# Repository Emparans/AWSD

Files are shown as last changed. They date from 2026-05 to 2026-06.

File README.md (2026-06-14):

# AWSD
### *Adventurer Who Solves Dungeons*

> Prototipo de robot autónomo para exploración de laberintos interactivos.

---

<div align="center">
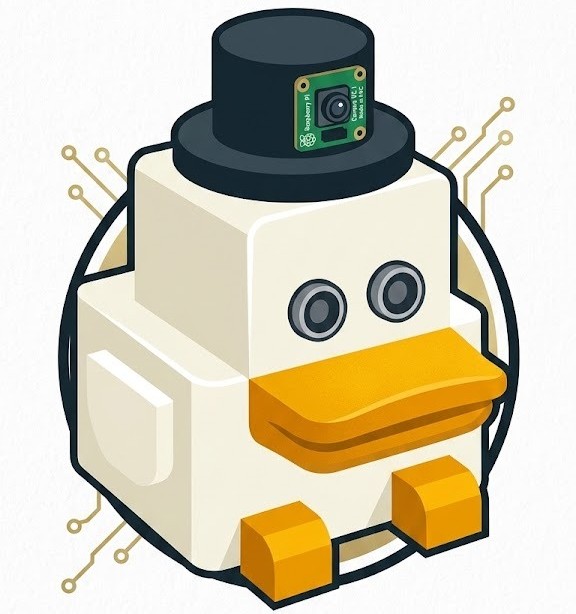
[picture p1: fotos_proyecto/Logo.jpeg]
LogoProyecto
  
</div>

# Descripción

AWSD (*Adventurer Who Solves Dungeons*) es un prototipo de robot autónomo diseñado para explorar laberintos de forma inteligente e interactiva. El proyecto combina robótica, visión artificial e interacción con el usuario para crear una experiencia inspirada en los videojuegos de aventuras.

Gracias a su cámara y a sus algoritmos de reconocimiento visual, el robot es capaz de analizar el entorno y localizar elementos importantes dentro del laberinto, como llaves necesarias para abrir puertas y avanzar en el recorrido.

Durante la exploración, AWSD encuentra distintos retos en forma de preguntas o pruebas que el usuario debe resolver para ayudar al robot a progresar. El objetivo del proyecto es integrar navegación autónoma, inteligencia artificial y gamificación en una experiencia educativa y entretenida.

---

# Foto Robot

<div align="center">
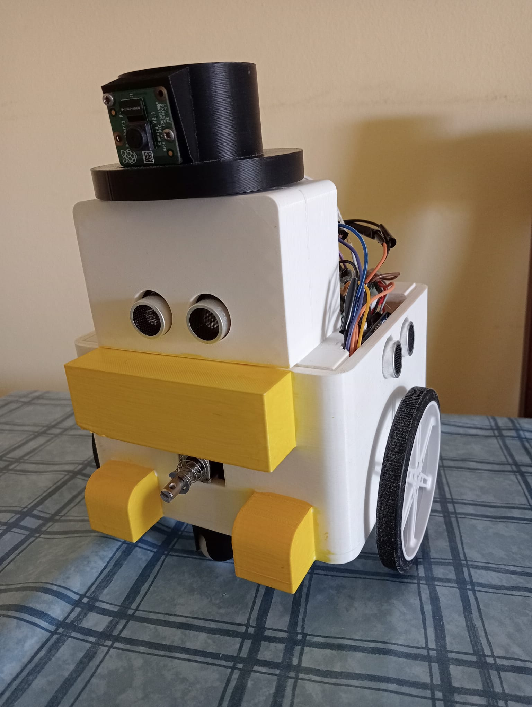
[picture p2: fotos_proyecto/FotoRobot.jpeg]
  
</div>

---

# Hardware

| Componente | Imagen | Descripción | Enlace |
|---|---|---|---|
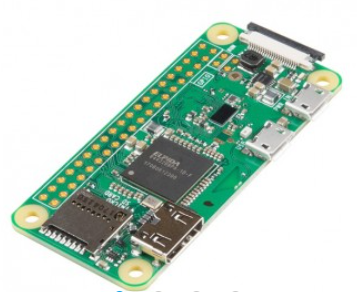
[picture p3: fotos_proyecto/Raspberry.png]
Raspberry
| **Raspberry Pi Zero W** |  | Cerebro del robot, gestiona la lógica y la conectividad Wifi. | [Ver Tienda](https://tienda.bricogeek.com/placas-raspberry-pi/1082-kit-basico-raspberry-pi-zero-wifi-microsd-32gb.html) |
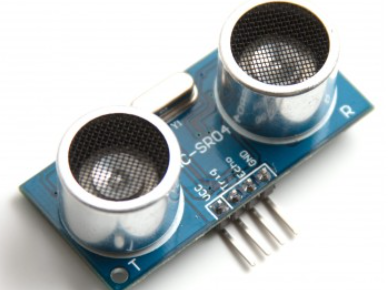
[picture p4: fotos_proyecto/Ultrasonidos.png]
Ultrasonidos
| **Sensor Ultrasonidos** |  | Mide las distancias para detectar las paredes del laberinto. | [Ver Tienda](https://tienda.bricogeek.com/sensores-distancia/741-sensor-de-distancia-por-ultrasonidos-hc-sr04.html) |
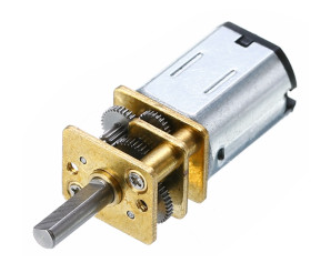
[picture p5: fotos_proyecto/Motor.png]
Motor
| **Motor N20 (6V 200 RPM)** |  | Motores con reductora metálica para el movimiento del chasis. | [Ver Tienda](https://tienda.bricogeek.com/motores-dc/1835-motor-n20-con-reductora-metalica-6v-200-rpm.html) |
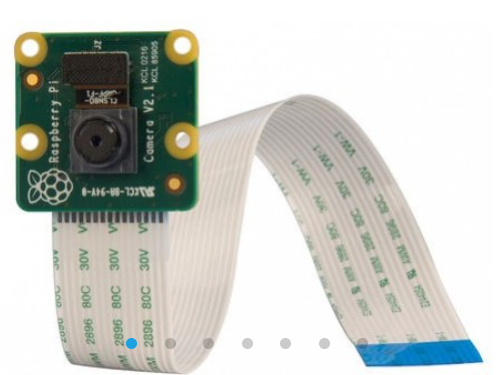
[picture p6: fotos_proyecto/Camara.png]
Camara
| **Cámara Raspberry Pi v2** |  | Captura imágenes en alta definición para la visión artificial. | [Ver Tienda](https://tienda.bricogeek.com/sensores-imagen/822-camara-raspberry-pi-v2-8-megapixels.html) |
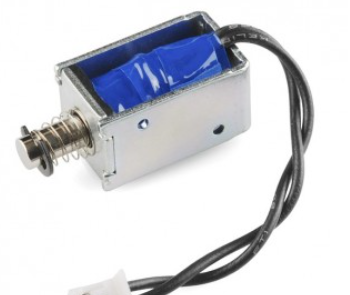
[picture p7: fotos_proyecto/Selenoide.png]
Selenoide
| **Solenoide 5V** |  | Actuador lineal para interactuar con los mecanismos del entorno. | [Ver Tienda](https://tienda.bricogeek.com/componentes/430-solenoide-5v.html) |
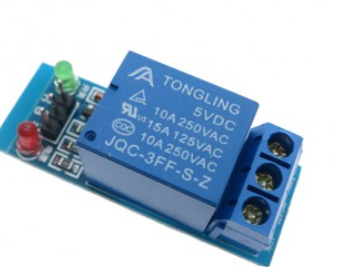
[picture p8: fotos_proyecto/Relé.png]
Relé
| **Módulo Relé** |  | Permite controlar el encendido del solenoide de forma segura. | [Ver Tienda](https://tienda.bricogeek.com/interruptores/1352-modulo-rele-5v.html) |
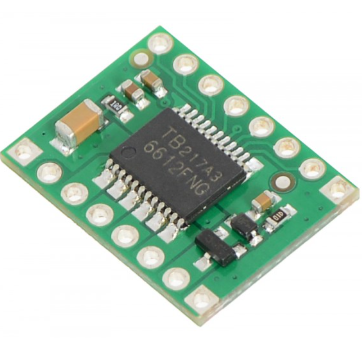
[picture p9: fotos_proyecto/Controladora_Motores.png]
ControladoraMotores
| **Controlador TB6612FNG** |  | Driver encargado de gestionar el sentido y velocidad de los motores. | [Ver Tienda](https://tienda.bricogeek.com/controladores-motores/999-controlador-de-motores-tb6612fng.html) |
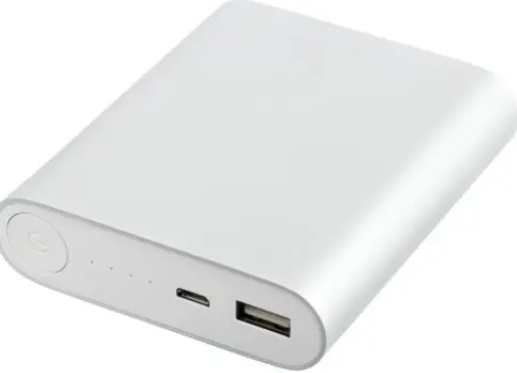
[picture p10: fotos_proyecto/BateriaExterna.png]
BateriaExterna
| **Batería Externa Anker** |  | Powerbank Slim encargada de alimentar la Raspberry Pi. | [Ver Tienda](https://www.amazon.es/Anker-PowerCore-Magnetic-Slim-B2C/dp/B099284SRR/) |
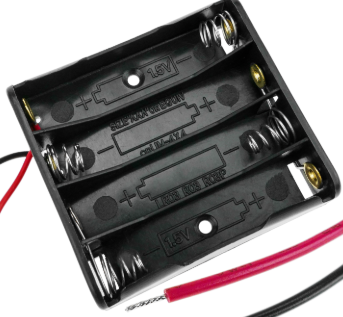
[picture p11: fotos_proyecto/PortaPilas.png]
PortaPilas
| **Porta Pilas 4xAA** |  | Soporte de baterías para la alimentación externa de los motores. | [Ver Tienda](https://tienda.bricogeek.com/componentes/160-base-para-baterias-4xaa.html) |
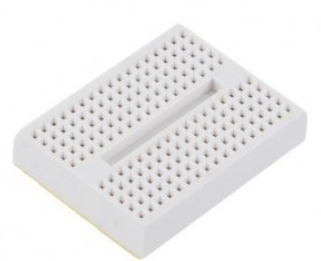
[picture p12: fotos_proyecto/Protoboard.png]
Protoboard
| **Mini Protoboard** |  | Placa de pruebas para realizar las conexiones eléctricas. | [Ver Tienda](https://tienda.bricogeek.com/herramientas-de-prototipado/211-mini-breadboard-adhesiva.html) |
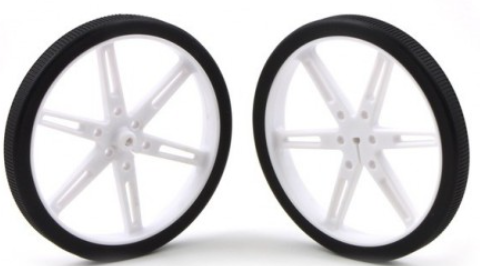
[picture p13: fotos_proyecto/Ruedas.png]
Ruedas
| **Ruedas (80x10mm)** |  | Pareja de ruedas principales acopladas a los motores N20. | [Ver Tienda](https://tienda.bricogeek.com/robotica/303-pareja-de-ruedas-80x10mm-blanco.html) |
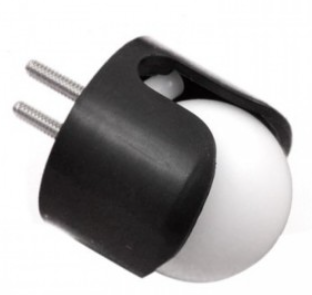
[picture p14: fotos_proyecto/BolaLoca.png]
RuedaLoca
| **Rueda Loca ABS** |  | Punto de apoyo pivotante trasero para dar estabilidad al robot. | [Ver Tienda](https://tienda.bricogeek.com/robotica/995-rueda-loca-plastico-abs-34.html) |

---

# Circuito Eléctrico

Diagrama de conexiones del sistema electrónico del robot.

<div align="center">
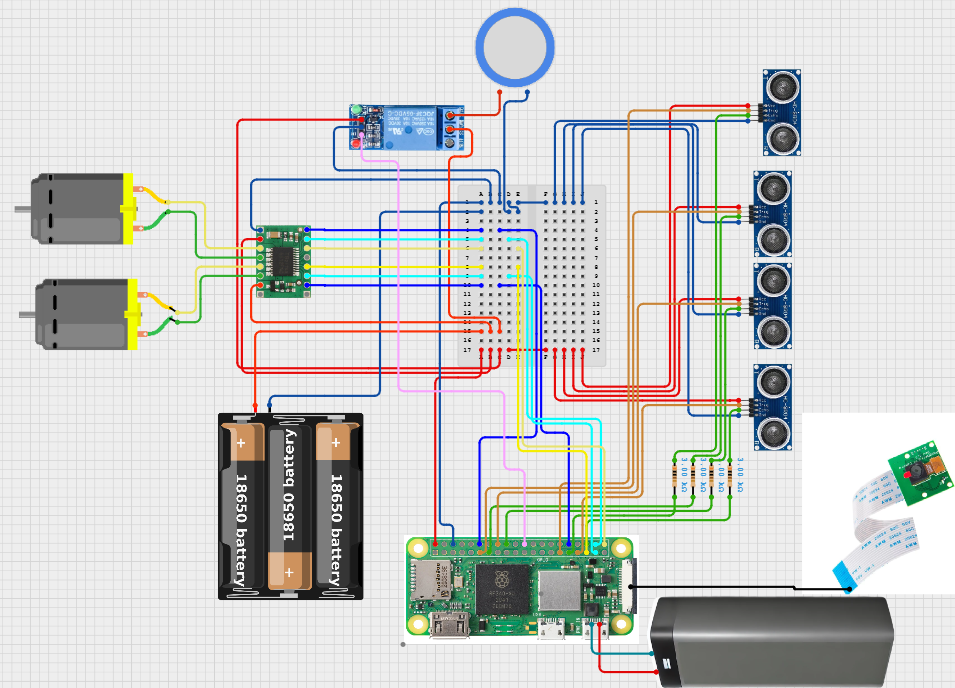
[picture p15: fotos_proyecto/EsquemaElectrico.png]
EsquemaElectrico
  
</div>

---

# Modelo 3D

Diseño 3D del chasis y componentes mecánicos del robot.

<div align="center">
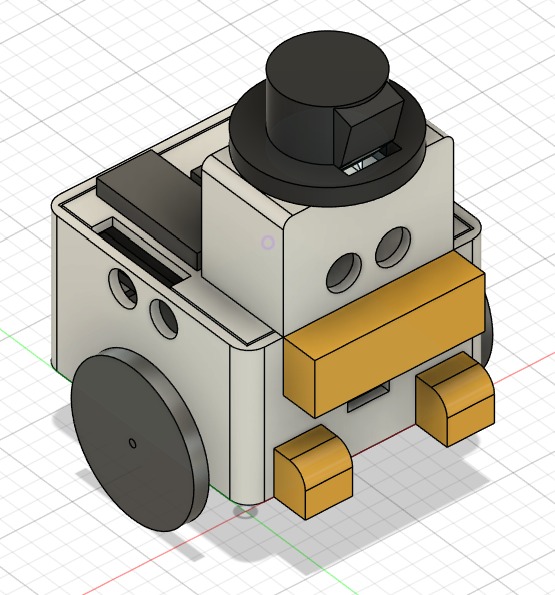
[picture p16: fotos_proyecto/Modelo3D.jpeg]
Modelo3D
  
</div>

---

# Arquitectura Software

Diagrama general de la arquitectura software del proyecto.

<div align="center">
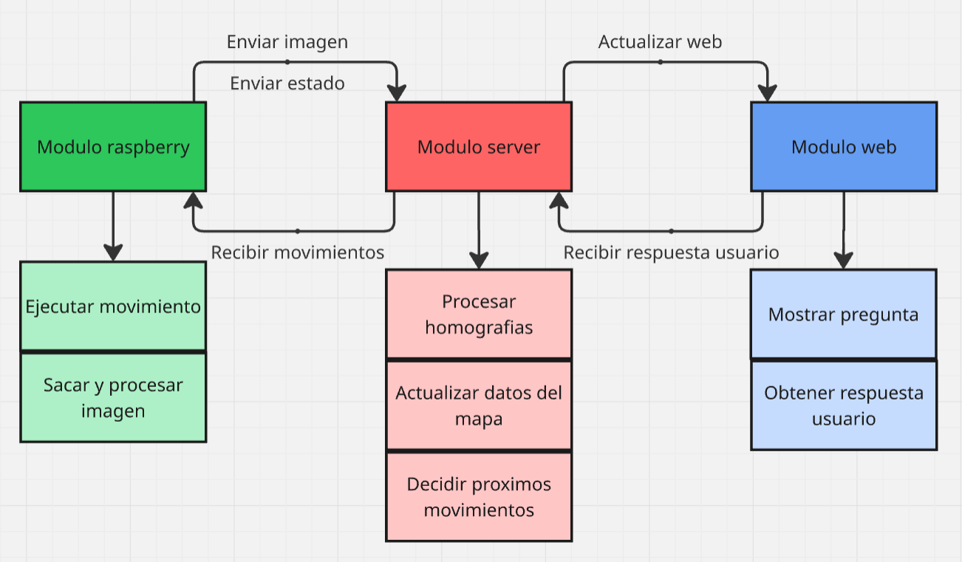
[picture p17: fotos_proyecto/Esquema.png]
Esquema
  
</div>

---

# Características

- Navegación autónoma en laberintos
- Reconocimiento visual mediante cámara
- Detección de llaves y puertas
- Interacción con el usuario mediante retos
- Arquitectura modular y escalable

---

# Referencias

- [@Rescue Maze Entry Presentation](https://www.youtube.com/watch?v=UpNFrBUcTxU&t=488s)
- [@The SECRET to Building a Maze Solving Robot](https://www.youtube.com/watch?v=Id-Xi8evfKU)
- [@Maze Navigating Robot Project With PicoBricks](https://picobricks.com/blogs/robotic-stem-projects/maze-solving-robot)
- [@Mec Robotics](https://www.micromice.org/)

---

# Autores

| Nombre | GitHub |
|---|---|
| Joan Aguilar Vilalta | [@JoanAV-H](https://github.com/JoanAV-H) |
| Gerard Benet Martinez | [@Gemarcx](https://github.com/Gemarcx) |
| Martí Barrio Galobardes | [@MBGit05](https://github.com/MBGit05) |
| Javier Emparan López | [@Emparans](https://github.com/Emparans) |

---

# Agradecimientos

Queremos agradecer a nuestros 3 profesores de la asignatura por ayudarnos en el proceso de creación de nuestro proyecto:

- Fernando Luis Vilariño Freire
- Carlos García Calvo
- Vernon Stanley Albayeros Duarte

# URL acceso a la web

¡Prueba la interfaz del proyecto en tiempo real! 

**[Acceder a la Web del Proyecto (Demo)](http://34.0.201.131:8080)**

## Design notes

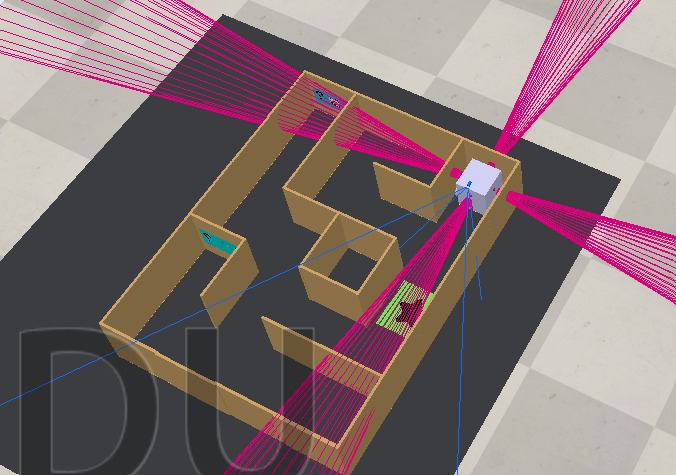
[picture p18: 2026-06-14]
Fotos_proyecto/FotoCoppelia.jpg

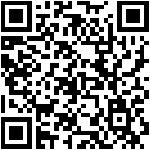
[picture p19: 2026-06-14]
Sim/texturas/preguntaEcuador.png

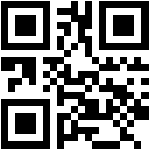
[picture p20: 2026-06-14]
Codigo/deteccion_de_objetos/Texturas/qr3.png

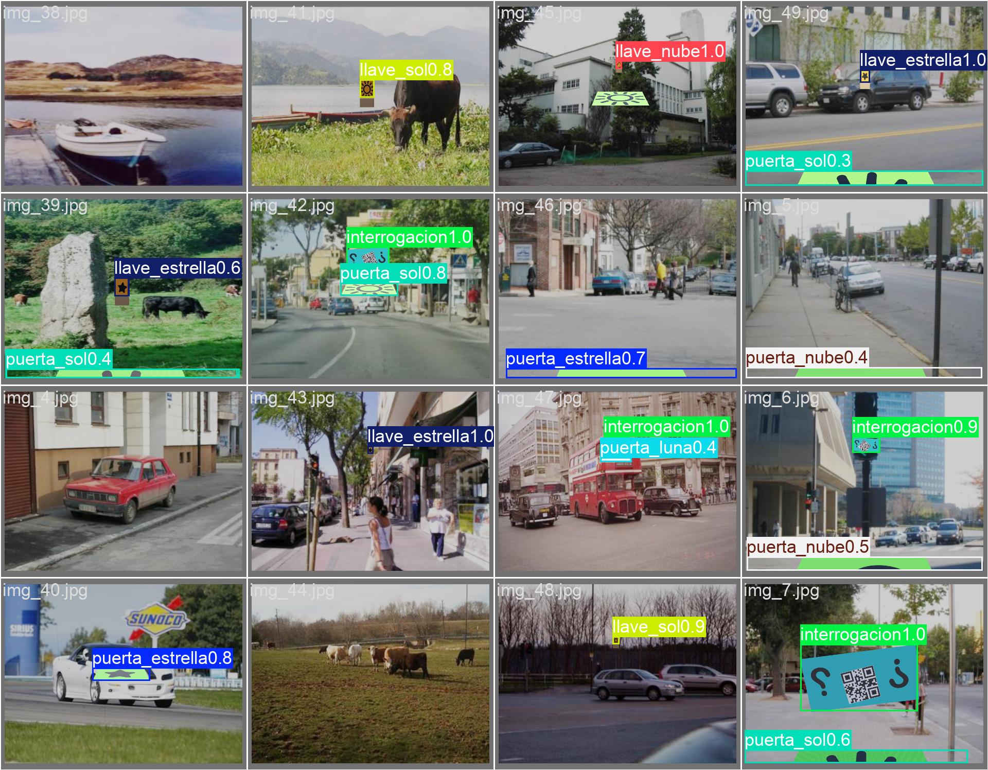
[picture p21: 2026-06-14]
Codigo/deteccion_de_objetos/modelo/val/val_batch2_pred.jpg

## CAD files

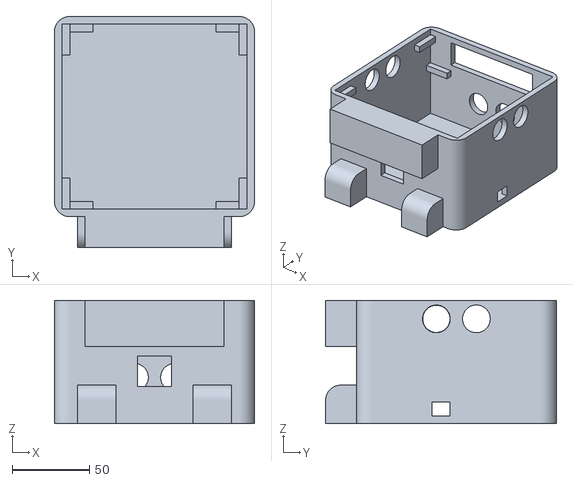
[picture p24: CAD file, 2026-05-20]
Modelos/Cuerpo.stl
130.0 x 150.0 x 80.0

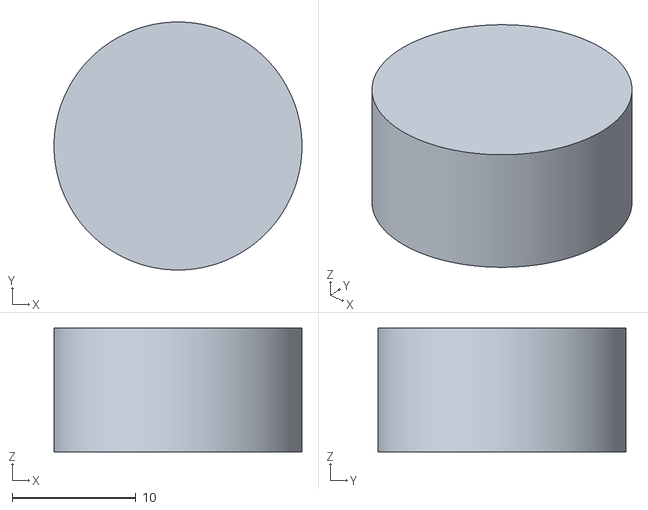
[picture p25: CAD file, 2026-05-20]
Modelos/SoporteBolaLocaFix.stl
20.0 x 20.0 x 10.0

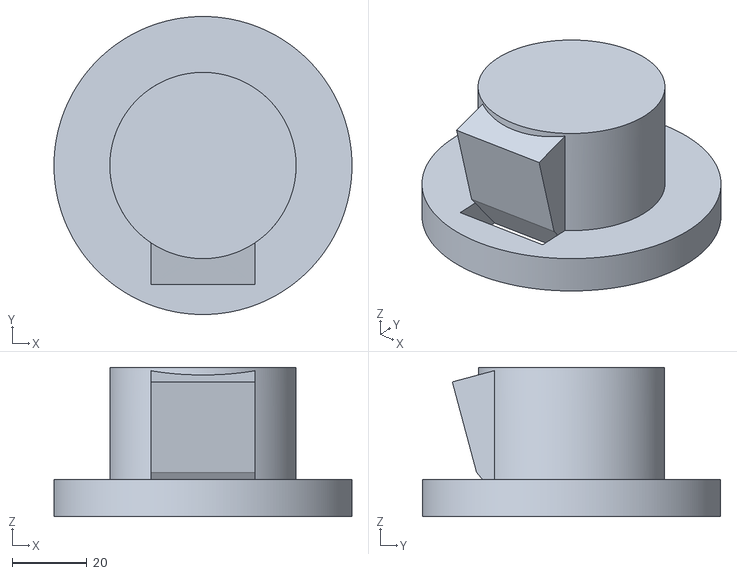
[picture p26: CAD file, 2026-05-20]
Modelos/Sombrero.stl
80.0 x 80.0 x 40.0

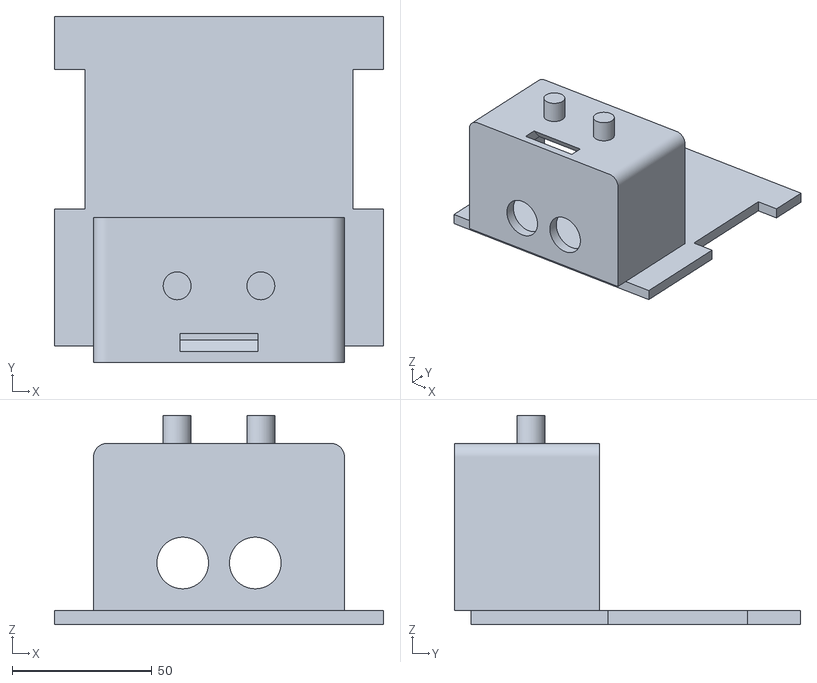
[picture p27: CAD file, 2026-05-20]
Modelos/CabezaFix.stl
118.0 x 124.0 x 75.0

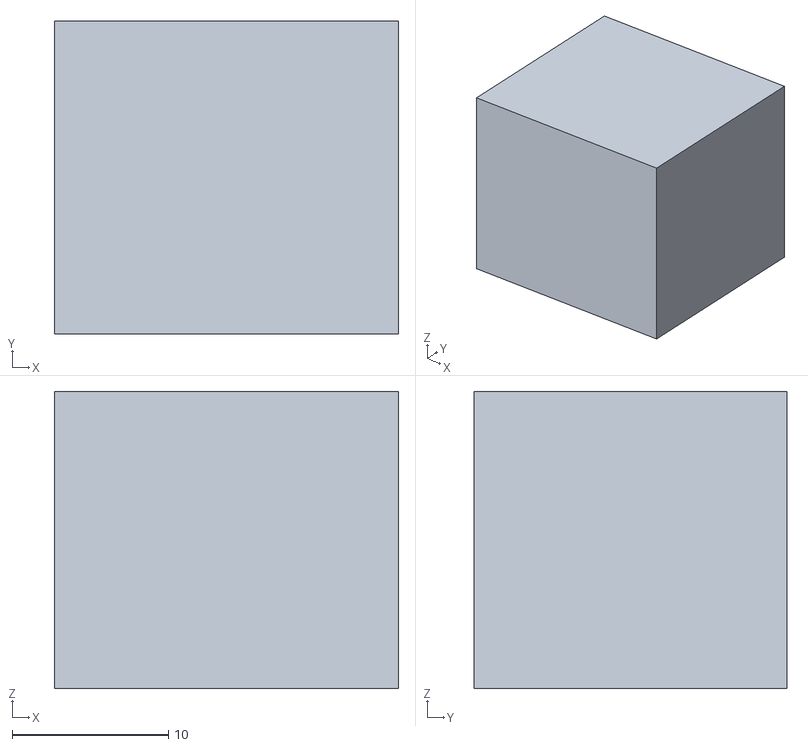
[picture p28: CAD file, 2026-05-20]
Modelos/SoporteSolenoide.stl
22.0 x 20.0 x 19.0

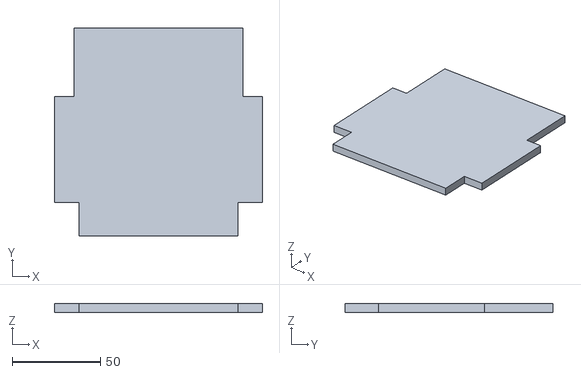
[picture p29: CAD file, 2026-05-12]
Modelos/Piso 1.stl
118.0 x 118.0 x 5.00

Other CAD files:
Codigo/deteccion_de_objetos/yoloTrain.blend

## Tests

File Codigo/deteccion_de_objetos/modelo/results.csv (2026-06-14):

epoch | time | train/box_loss | train/cls_loss | train/dfl_loss | metrics/precision(B) | metrics/recall(B) | metrics/mAP50(B) | metrics/mAP50-95(B) | val/box_loss | val/cls_loss | val/dfl_loss | lr/pg0 | lr/pg1 | lr/pg2
1 | 70.828 | 0.81072 | 21.0906 | 0.01065 | 0.65423 | 0.11738 | 0.12236 | 0.09675 | 0.50373 | 10.9561 | 0.0079 | 0.00023839 | 0.00023839 | 0.00023839
2 | 96.2362 | 0.60137 | 9.27073 | 0.00528 | 0.13959 | 0.40847 | 0.34422 | 0.30862 | 0.50569 | 3.52162 | 0.00798 | 0.000474877 | 0.000474877 | 0.000474877
3 | 128.642 | 0.72751 | 4.66279 | 0.00694 | 0.65075 | 0.54399 | 0.6643 | 0.54264 | 0.76318 | 1.58106 | 0.01133 | 0.00070162 | 0.00070162 | 0.00070162
4 | 160.816 | 0.77086 | 2.86881 | 0.0062 | 0.70629 | 0.67216 | 0.77792 | 0.66259 | 0.64058 | 1.10132 | 0.00977 | 0.000723321 | 0.000723321 | 0.000723321
5 | 192.011 | 0.65308 | 2.25663 | 0.00621 | 0.64105 | 0.72513 | 0.71912 | 0.6311 | 0.6069 | 1.06114 | 0.00762 | 0.000708095 | 0.000708095 | 0.000708095
6 | 223.237 | 0.70648 | 1.83951 | 0.00611 | 0.78201 | 0.6145 | 0.82236 | 0.7171 | 0.59879 | 1.05961 | 0.01123 | 0.000692869 | 0.000692869 | 0.000692869
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

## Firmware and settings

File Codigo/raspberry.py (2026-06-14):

import requests
from pathlib import Path
import cv2
import numpy as np
import time
import websocket

import math
import time
from gpiozero import DistanceSensor, OutputDevice, PWMOutputDevice
from picamera2 import Picamera2

SERVER_URL = "http://34.0.201.131:8080/raspberry"
WS_VIDEO_URL = "ws://34.0.201.131:8080/control/video_stream"

imageForProcessingName = "proc"
outputCameraRes = (820, 616)
real = Path(__file__).parent / "real"

tempDir = 'r'
tempPos = (0, 0)
lastTurn = 'X'

llaveHeld = 1

def sacar_foto():
    print("Activando sensor de cámara...")
    try:
        picam.start()
        time.sleep(1.2)  # Tiempo para que el sensor regule la luz ambiental
        
        unfiltered_array = picam.capture_array("main")
        
        picam.stop()
        print("Sensor en reposo. Procesando bytes...")
                
                
        scaled_array = unfiltered_array[::4, ::4]
        return scaled_array
                
    except Exception as e:
        print(f"Error en el ciclo de captura: {e}")
        try: picam.stop()
        except: pass
    time.sleep(1)

def obtener_distancia(nombre):
    mapeo_sensores = {
        "Izquierda": "Derecha",
        "Derecha": "Izquierda"
    }
    sensor_key = mapeo_sensores.get(nombre, nombre)
    s = sensores[sensor_key]
    distancia = s.distance * 100 if s.distance is not None else 999.0
    
    if nombre == "Derecha":
        distancia += 1
    return distancia

def configurar_direcciones(a1, a2, b1, b2):
    mA_in1.value, mA_in2.value = a1, a2
    mB_in1.value, mB_in2.value = b1, b2

def detener_motores():
    mA_pwm.value = mB_pwm.value = 0.0
    configurar_direcciones(0, 0, 0, 0)


def girar_suave(grados=90, direccion="derecha", tiempo_estimado=0.45):
    global llaveHeld
    tiempo_estimado = tiempo_estimado * max((llaveHeld / 1.1),1)
    print(f"Giro hacia la {direccion}...")
    dir_giro = (1, 0, 0, 1) if direccion == "derecha" else (0, 1, 1, 0)
    dir_atras = (0, 1, 1, 0) if direccion == "derecha" else (1, 0, 0, 1)

    sensores_prioridad = ["Inferior", "Izquierda", "Derecha", "Delantero"] 
    distancias = {sensor: obtener_distancia(sensor) for sensor in sensores_prioridad}
    sensorIdeal = "Inferior"

    for sensor, valor in distancias.items():
        print(f"-{sensor}: {valor:.2f} cm")

    if(tiempo_estimado < 0.5):
        if(direccion=="derecha"):
            if distancias["Izquierda"] < 10:
                if(distancias["Delantero"] < distancias["Izquierda"]):
                    sensorIdeal = "Derecha"
                else:
                    sensorIdeal = "Inferior"
            else:
                sensorIdeal = "Derecha"

        elif(direccion=="izquierda"):
            if distancias["Derecha"] < 10:
                if(distancias["Delantero"] < distancias["Derecha"]):
                    sensorIdeal = "Izquierda"
                else:
                    sensorIdeal = "Inferior"
            else:
                sensorIdeal = "Izquierda"
    
    print(f"Sensor Ideal: {sensorIdeal}")

    #Giro grueso
    configurar_direcciones(*dir_giro)
    t0 = time.time()
    while (time.time() - t0) < tiempo_estimado:
        progreso = (time.time() - t0) / tiempo_estimado
        mA_pwm.value = mB_pwm.value = max(0.0, min(1.0, 0.15 + 0.55 * math.sin(progreso * math.pi)))
        time.sleep(0.02)
    detener_motores()
    time.sleep(0.3)

    #Barrido
    configurar_direcciones(*dir_atras) 
    mA_pwm.value = mB_pwm.value = 0.30 
    time.sleep(0.40)                    
    detener_motores()
    time.sleep(0.15)
    
    configurar_direcciones(*dir_giro) 
    mA_pwm.value = mB_pwm.value = 0.16 * max((llaveHeld / 1.7),1)
    dist_minima = obtener_distancia(sensorIdeal)
    inicio_escaneo = time.time()

    while True:
        dist_actual = obtener_distancia(sensorIdeal)
        if dist_actual == 999.0: continue
        if dist_actual < dist_minima: dist_minima = dist_actual
        if (time.time() - inicio_escaneo) > 1.45 and dist_actual > (dist_minima + 0.4): break
        time.sleep(0.01)

    #Corrección final
    configurar_direcciones(*dir_atras) 
    mA_pwm.value = mB_pwm.value = 0.55  
    time.sleep(0.08 * max((llaveHeld / 1.3),1))                    
    detener_motores()
    time.sleep(0.2)

def avanzar_corrigiendo(distancia_cm=56, potenciaMax = 0.45, target_frontal=None):
    global llaveHeld
    distancia_cm = distancia_cm * max((llaveHeld / 1.5),1)
    potenciaMax = potenciaMax * max((llaveHeld / 1.5),1)
    tiempo_estimado = (abs(distancia_cm) * 1.5) / 50.0
    print(f"[~] Avanzando {distancia_cm}cm...")
    Kp, Kd = 0.008, 0.008
    UMBRAL_PARED, TARGET_CERCA, POTENCIA_FINA = 15.0, 5.0, 0.15 * llaveHeld
    dist_izq_ant = dist_der_ant = None

    #Avance grueso
    if distancia_cm >= 0:
        configurar_direcciones(1, 0, 1, 0)
    else:
        configurar_direcciones(0, 1, 0, 1)
        
    t0 = time.time()
    while (time.time() - t0) < tiempo_estimado:
        progreso = (time.time() - t0) / tiempo_estimado
        potencia = max(0.0, min(1.0, 0.15 + potenciaMax * math.sin(progreso * math.pi)))
        cambio_izq = cambio_der = correccion = 0.0
        
        dist_izq, dist_der = obtener_distancia("Izquierda"), obtener_distancia("Derecha")
        if dist_izq < UMBRAL_PARED:
            if dist_izq_ant is not None and dist_izq_ant < UMBRAL_PARED: cambio_izq = dist_izq - dist_izq_ant  
            correccion += ((dist_izq - TARGET_CERCA) * Kp) + (cambio_izq * Kd)
            dist_izq_ant = dist_izq
        else: dist_izq_ant = None 

        if dist_der < UMBRAL_PARED:
            if dist_der_ant is not None and dist_der_ant < UMBRAL_PARED: cambio_der = dist_der - dist_der_ant  
            correccion -= ((dist_der - TARGET_CERCA) * Kp) + (cambio_der * Kd)
            dist_der_ant = dist_der
        else: dist_der_ant = None

        if distancia_cm < 0:
            correccion = -correccion

        mA_pwm.value = max(0.12, min(0.95, potencia - (correccion * max((llaveHeld / 1.5),1) - 0.01)))
        mB_pwm.value = max(0.12, min(0.95, potencia + (correccion * max((llaveHeld / 1.5),1))))
        time.sleep(0.02)

    detener_motores()
    time.sleep(0.2)

    #Ajuste longitudinal fino
    dist_del, dist_tras = obtener_distancia("Delantero"), obtener_distancia("Inferior")
    sensor_elegido = "Delantero" if dist_del < dist_tras else "Inferior"
    dist_inicial = dist_del if dist_del < dist_tras else dist_tras

    if dist_inicial > 45.0:
        detener_motores()
        return

    if target_frontal is not None:
        target = target_frontal
    else:
        target = 5.0 if dist_inicial < 17.5 else 30.0
        
    dist_izq_ant = dist_der_ant = None
    target_izq = obtener_distancia("Izquierda") if obtener_distancia("Izquierda") < UMBRAL_PARED else TARGET_CERCA
    target_der = obtener_distancia("Derecha") if obtener_distancia("Derecha") < UMBRAL_PARED else TARGET_CERCA

    while True:
        dist_actual = obtener_distancia(sensor_elegido)
        error = dist_actual - target
        if abs(error) < 0.5: break

        moviendo_adelante = True
        if sensor_elegido == "Delantero":
            if error > 0: configurar_direcciones(1, 0, 1, 0)
            else: configurar_direcciones(0, 1, 0, 1); moviendo_adelante = False
        else: 
            if error > 0: configurar_direcciones(0, 1, 0, 1); moviendo_adelante = False
            else: configurar_direcciones(1, 0, 1, 0)

        dist_izq, dist_der = obtener_distancia("Izquierda"), obtener_distancia("Derecha")
        correccion_lateral = 0.0

        if dist_izq < UMBRAL_PARED:
            cambio_izq = (dist_izq - dist_izq_ant) if dist_izq_ant is not None else 0.0
            correccion_lateral += (dist_izq - target_izq) * Kp + (cambio_izq * Kd)
            dist_izq_ant = dist_izq
            
        if dist_der < UMBRAL_PARED:
            cambio_der = (dist_der - dist_der_ant) if dist_der_ant is not None else 0.0
            correccion_lateral -= (dist_der - target_der) * Kp + (cambio_der * Kd)
            dist_der_ant = dist_der

        if not moviendo_adelante: correccion_lateral = -correccion_lateral

        mA_pwm.value = max(0.10, min(0.25, POTENCIA_FINA - correccion_lateral))
        mB_pwm.value = max(0.10, min(0.25, POTENCIA_FINA + correccion_lateral))
        time.sleep(0.01)

    detener_motores()
    time.sleep(0.2)
    
imageID = 0
def generate_mapping_sources(img):
    global imageID
    """Genera la homografía en blanco y negro para el análisis del mapa."""
    outputXSize = 800
    latRate = 1/4 
    nTilesInVArea = 4.5
    latMargin = outputXSize * latRate / 2
    outputYSize = int((outputXSize - (2 * latMargin)) * nTilesInVArea)
    WIDTH, HEIGHT = outputXSize, outputYSize
    
    if img is None:
        print("Error: Imagen no recibida correctamente.")
        return None

    try:
        from pathlib import Path
        directorio = Path(__file__).parent
    except NameError:
        import os
        directorio = os.getcwd()
    except Exception as e:
        print(f"Error inesperado con la ruta: {e}")
        directorio = ""

    ruta_salida2 = f"{directorio}/normal.jpg"

    # 3. Exportar y verificar éxito
    exito2 = cv2.imwrite(ruta_salida2, img)

    Base_W, Base_H = 3280, 2464
    h, w = img.shape[:2]
    scale_x, scale_y = w / Base_W, h / Base_H

    pts_src = np.array([[68, 2463], [3182, 2463], [1820, 880], [1332, 880]], dtype=np.float32)
    pts_src[:, 0] *= scale_x  
    pts_src[:, 1] *= scale_y  

    pts_dst = np.array([[latMargin, HEIGHT], [WIDTH - latMargin, HEIGHT], [WIDTH - latMargin, 0], [latMargin, 0]], dtype=np.float32)
    H = cv2.getPerspectiveTransform(pts_src, pts_dst)
    
    processed_orig = cv2.cvtColor(img, cv2.COLOR_BGR2HSV)
    if imageID == 6:
        lower_brown = np.array([0, 0, 0])
        upper_brown = np.array([105, 90, 255])
    else:
        
        lower_brown = np.array([0, 0, 0])
        upper_brown = np.array([45, 255, 255])
    imageID += 1


    mask_orig = cv2.inRange(processed_orig, lower_brown, upper_brown)
    
    mask_temp = cv2.warpPerspective(mask_orig, H, (WIDTH, HEIGHT), borderValue=0)
    kernel = np.ones((9,9), np.uint8)
    mask_temp = cv2.morphologyEx(mask_temp, cv2.MORPH_OPEN, kernel)
    mask_temp = cv2.morphologyEx(mask_temp, cv2.MORPH_CLOSE, kernel)

    bottom_30 = int(HEIGHT * 0.7)
    edges = cv2.Canny(mask_temp[bottom_30:, :], 50, 150)
    lines = cv2.HoughLinesP(edges, 1, np.pi/180, threshold=80, minLineLength=40, maxLineGap=10)
    
    angles = []
    if lines is not None:
        for line in lines:
            x1, y1, x2, y2 = line[0]
            if y2 > y1: x1, y1, x2, y2 = x2, y2, x1, y1
            dx, dy = x2 - x1, y1 - y2
            if dx != 0 or dy != 0:
                tilt = 90.0 - np.degrees(np.arctan2(dy, dx))
                if -5 < tilt < 5: angles.append(tilt)

    best_tilt = np.median(angles) if angles else 0
        
    bottom_15 = int(HEIGHT * 0.85)
    col_sums = np.mean(mask_temp[bottom_15:, :], axis=0)
    is_wall = col_sums > (255 * 0.3)
    mid_x = WIDTH // 2
    
    left_wall_x, left_wall_found = 0, False
    for x in range(mid_x, -1, -1):
        if is_wall[x]: left_wall_x, left_wall_found = x, True; break
            
    right_wall_x, right_wall_found = WIDTH - 1, False
    for x in range(mid_x, WIDTH):
        if is_wall[x]: right_wall_x, right_wall_found = x, True; break

    shift_x = 0
    if left_wall_found and right_wall_found:
        shift_x = mid_x - ((left_wall_x + right_wall_x) // 2)
    elif left_wall_found:
        shift_x = int(latMargin) - left_wall_x
    elif right_wall_found:
        shift_x = int(WIDTH - latMargin) - right_wall_x
    
    M_rot = cv2.getRotationMatrix2D((WIDTH // 2, HEIGHT), best_tilt, 1.0)
    H_final = np.vstack([M_rot, [0, 0, 1]])
    H_final = np.vstack([[[1, 0, shift_x], [0, 1, 0]], [0, 0, 1]]) @ H_final @ H
    
    mask_final = cv2.warpPerspective(mask_orig, H_final, (WIDTH, HEIGHT), borderValue=0)
    mask_final = cv2.morphologyEx(mask_final, cv2.MORPH_CLOSE, kernel)
    
    print("INFO: Procesamiento morfológico terminado. Dibujando puntos...")

    # 1. Convertir la máscara a 3 canales para poder dibujar en rojo
    mask_color = cv2.cvtColor(mask_final, cv2.COLOR_GRAY2BGR)

    interpretationSpots = np.array([
    # MIDDLE
    [400, 2699], [400, 2650], [400, 2500], [400, 2300],
    [400, 1900], [400, 1700], [400, 1300], [400, 1100],
    [400,  700], [400,  500],

    # LEFT
    [75, 2650], [75, 2250], [75, 1700], [75,  1150],
    [75,   600],

    # RIGHT
    [700, 2650], [700, 2250], [700, 1700], [700,  1150],
    [700,   600]
    ], dtype=np.int32)

    lado = 51
    mitad = lado // 2
    color_rojo = (0, 0, 255)
    
    for (x, y) in interpretationSpots:
        pt1 = (x - mitad, y - mitad)
        pt2 = (x + mitad, y + mitad)
        cv2.rectangle(mask_color, pt1, pt2, color_rojo, thickness=-1)

    print("INFO: Puntos dibujados. Preparando exportación...")

    # 2. Sistema a prueba de fallos para la ruta
    try:
        from pathlib import Path
        directorio = Path(__file__).parent
    except NameError:
        import os
        directorio = os.getcwd()
    except Exception as e:
        print(f"Error inesperado con la ruta: {e}")
        directorio = ""

    ruta_salida = f"{directorio}/img_dotted.jpg"

    # 3. Exportar y verificar éxito
    exito = cv2.imwrite(ruta_salida, mask_color)
    
    if exito:
        print(f"ÉXITO TOTAL: Imagen guardada en:\n -> {ruta_salida}")
    else:
        print(f"ERROR CRÍTICO: cv2.imwrite falló. Comprueba que tienes permisos de escritura en:\n -> {ruta_salida}")

    return mask_final

def moveForward(nTiles):
    global tempPos, lastTurn
    if nTiles == 0: return
    
    additions = {'u': (0, 1), 'r': (1, 0), 'd': (0, -1), 'l': (-1, 0)}
    addition = additions.get(tempDir, (0, 0))

    avanzar_corrigiendo(DISTANCIA_CASILLA * nTiles)

    tempPos = (tempPos[0] + addition[0] * nTiles, tempPos[1] + addition[1] * nTiles)
    sync_position_with_server()
        
    lastTurn = 'X'
    time.sleep(0.5)

def turnLeft():
    global tempDir, lastTurn
    trans = {'u': 'l', 'r': 'u', 'd': 'r', 'l': 'd'}
    tempDir = trans.get(tempDir, tempDir)
    sync_position_with_server()
    girar_suave(direccion="izquierda", tiempo_estimado=TIEMPO_GIRO_NORMAL)
    lastTurn = 'l'
    time.sleep(0.5)

def turnRight():
    global tempDir, lastTurn
    trans = {'u': 'r', 'r': 'd', 'd': 'l', 'l': 'u'}
    tempDir = trans.get(tempDir, tempDir)
    sync_position_with_server()
    girar_suave(direccion="derecha", tiempo_estimado=TIEMPO_GIRO_NORMAL)
    lastTurn = 'r'
    time.sleep(0.5)

def turnBack():
    global tempDir
    trans = {'u': 'd', 'r': 'l', 'd': 'u', 'l': 'r'}
    tempDir = trans.get(tempDir, tempDir)
    sync_position_with_server()
    girar_suave(direccion="izquierda", tiempo_estimado=TIEMPO_GIRO_180)
    lastTurn = 'r'
    time.sleep(0.5)


def pickUpKey():
    global llaveHeld
    print("Llave Held")
    llaveHeld = 1.8
    rele.on()
    time.sleep(0.1)
    avanzar_corrigiendo(distancia_cm=20, potenciaMax=0.25)
    time.sleep(0.1)
    avanzar_corrigiendo(distancia_cm=-20, potenciaMax=0.25, target_frontal=10)

def openDoor():
    global llaveHeld
    print("Llave no held")
    girar_suave(direccion="derecha", tiempo_estimado=TIEMPO_GIRO_NORMAL)
    time.sleep(1)
    avanzar_corrigiendo(distancia_cm=15, potenciaMax=0.25)
    time.sleep(0.5)
    llaveHeld = 1
    rele.off()
    time.sleep(0.5)
    avanzar_corrigiendo(distancia_cm=-10, potenciaMax=0.25)
    time.sleep(1)
    girar_suave(direccion="izquierda", tiempo_estimado=TIEMPO_GIRO_NORMAL)

# --- Peticiones de Análisis a la VM ---
def sync_position_with_server():
    try:
        requests.post(f"{SERVER_URL}/update_position", json={"pos": list(tempPos), "dir": tempDir}, timeout=2)
    except requests.exceptions.RequestException: pass

def check_robot_pause():
    try:
        res = requests.get(f"{SERVER_URL}/estado_pausa", timeout=2)
        if res.status_code == 200:
            return res.json().get('pausa', False)
    except requests.exceptions.RequestException:
        pass
    return False

def send_robot_step(homography, resized):
    print("Enviando imágenes de análisis a la VM...")
    try:
        _, cenital_buf = cv2.imencode('.jpg', homography)
        _, resized_buf = cv2.imencode('.jpg', resized)
        
        files = {
            "cenital_img": (f"{imageForProcessingName}_cenitalBW.jpg", cenital_buf.tobytes(), "image/jpeg"),
            "resized_img": (f"{imageForProcessingName}_resized.jpg", resized_buf.tobytes(), "image/jpeg")
        }
        res = requests.post(f"{SERVER_URL}/analyze", files=files, data={"img_name": imageForProcessingName})
        if res.status_code == 200:
            data = res.json()
            return data.get('destination_type'), data.get('commands', [])
    except requests.exceptions.RequestException as e:
        print(f"Error de conexión analizando paso: {e}")
    return None, None

def skip_robot_step():
    print("Saltando paso (Cálculo remoto de ruta)...")
    try:
        res = requests.post(f"{SERVER_URL}/next_route")
        if res.status_code == 200:
            data = res.json()
            return data.get('destination_type'), data.get('commands', [])
    except requests.exceptions.RequestException as e:
        print(f"Error de conexión saltando paso: {e}")
    return None, None

def send_reset_command():
    global tempPos, tempDir
    tempDir, tempPos = 'r', (0, 0)
    print("Enviando comando de reinicio a la VM...")
    try:
        res = requests.post(f"{SERVER_URL}/reset")
        if res.status_code == 200:
            print(f"Servidor reiniciado: {res.json().get('message')}")
    except requests.exceptions.RequestException:
        print("Imposible conectar con FastAPI para realizar Reset.")

def executeCommands(commands):
    if not commands: return
    for cmd in commands:
        action, steps = cmd[0], int(cmd[1])
        if action == 'r': turnRight()
        elif action == 'l': turnLeft()
        elif action == 'b': turnBack()
        moveForward(steps)
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

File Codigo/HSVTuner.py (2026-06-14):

import cv2
import numpy as np
from pathlib import Path

def nothing(x):
    pass

# Load your REAL image here

imgName = "test"
input_path = f"{Path(__file__).parent}/testOutput/{imgName}.jpg"

img = cv2.imread(input_path)
if img is None:
    print(f"No se pudo cargar la imagen en {input_path}")
    exit()

img = cv2.resize(img, (800, 600))
hsv = cv2.cvtColor(img, cv2.COLOR_BGR2HSV)

cv2.namedWindow('HSV Tuner')

# Create trackbars for color change
cv2.createTrackbar('HMin', 'HSV Tuner', 0, 179, nothing)
cv2.createTrackbar('SMin', 'HSV Tuner', 0, 255, nothing)
cv2.createTrackbar('VMin', 'HSV Tuner', 0, 255, nothing)
cv2.createTrackbar('HMax', 'HSV Tuner', 179, 179, nothing)
cv2.createTrackbar('SMax', 'HSV Tuner', 255, 255, nothing)
cv2.createTrackbar('VMax', 'HSV Tuner', 255, 255, nothing)

# Set default values for Max HSV
cv2.setTrackbarPos('HMax', 'HSV Tuner', 179)
cv2.setTrackbarPos('SMax', 'HSV Tuner', 255)
cv2.setTrackbarPos('VMax', 'HSV Tuner', 255)

while True:
    hMin = cv2.getTrackbarPos('HMin', 'HSV Tuner')
    sMin = cv2.getTrackbarPos('SMin', 'HSV Tuner')
    vMin = cv2.getTrackbarPos('VMin', 'HSV Tuner')
    hMax = cv2.getTrackbarPos('HMax', 'HSV Tuner')
    sMax = cv2.getTrackbarPos('SMax', 'HSV Tuner')
    vMax = cv2.getTrackbarPos('VMax', 'HSV Tuner')

    lower = np.array([hMin, sMin, vMin])
    upper = np.array([hMax, sMax, vMax])

    mask = cv2.inRange(hsv, lower, upper)
    result = cv2.bitwise_and(img, img, mask=mask)

    cv2.imshow('HSV Tuner', mask)
    cv2.imshow('Mask', mask)

    if cv2.waitKey(1) & 0xFF == ord('q'):
        print(f"New Lower: [{hMin}, {sMin}, {vMin}]")
        print(f"New Upper: [{hMax}, {sMax}, {vMax}]")
        break

cv2.destroyAllWindows()

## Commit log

2026-05-05 V1. Generacion de banco de imagenes y modelo YOLO
    [results.csv, yoloTrain.blend]
2026-05-12 añadir modelos
    [Cabeza.stl, Cuerpo.stl, Piso 1.stl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]
2026-05-20 version final de los modelos, arreglados
    [Cabeza.stl, CabezaFix.stl, Cuerpo.stl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]
2026-05-20 Generacion completa de dataset. Modelo actualizado y validado
    [results.csv, yoloTrain.blend]
2026-05-22 Entorno de simulacion creado
2026-05-27 Created raspberry pi simulation
2026-06-01 versiones sin interacciones del entorno de moverCasilla y girar
2026-06-03 Server logic added and improved raspberry pi functionality
2026-06-04 Qr reading and fixed motors with gpiozero
    [P_motor.py, simulate_pi.py]
2026-06-06 añadido funciones para tomar foto y manejo de ruedas
2026-06-07 Primera version de la funcion calibrate
2026-06-07 fix dependencia de fps
2026-06-10 Simulate cleaned and camera fixed
    [simulate_pi.py]
2026-06-13 codigo raspberry final
2026-06-14 Project cleaning
    [results.csv]
